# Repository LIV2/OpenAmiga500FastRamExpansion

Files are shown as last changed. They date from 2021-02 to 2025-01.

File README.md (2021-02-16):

# OpenAmiga500FastRamExpansion
OpenAmiga500FastRamExpansion is an Open Hardware 4/8 MB Fast RAM Expansion for the Commodore Amiga 500 Computer.

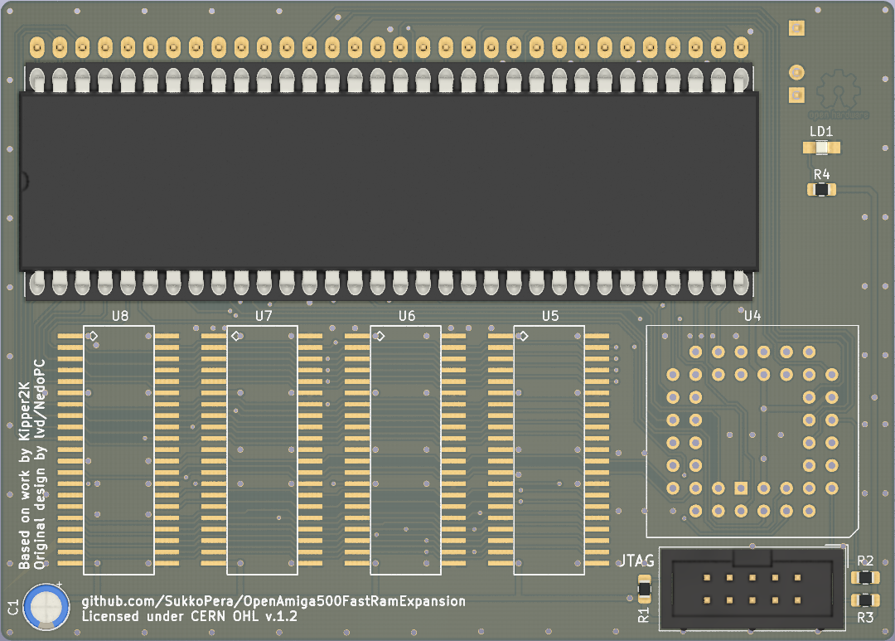
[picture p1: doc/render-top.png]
Board


### Summary
Most low-end Amiga models only came with *Chip RAM*. "Big Box" models allowed for a different type of memory to be installed, known as *Fast RAM*, where *fast* means that it's dedicated to the main processor, so that it doesn't have to compete with the other chips in order to gain access to it (as is the case with Chip RAM). While both Chip and Fast RAM are limited in size, you can have at least a few MB of the latter on all Amigas (usually up to 8), while the former can never exceed 2 MB.

OpenAmiga500FastRamExpansion will allow you to add up to 4 or 8 MB of Fast RAM to your Amiga 500. This way you will be able to run more applications at once and more quickly. If you combine it with [a chip RAM expansion](http://eab.abime.net/showthread.php?t=85395), you will also be able to run almost all games supported by WHDLoad, pushing your Amiga to its limits. 

OpenAmiga500FastRamExpansion is basically a clone of [a RAM expansion produced by Kipper2K a few years ago](http://eab.abime.net/showthread.php?t=64218), based on [an earlier design by lvd/NedoPC](http://lvd.nedopc.com/Projects/a600_8mb/index.html). He has since stopped producing and selling these cards and I thought it was a pity that he didn't open his designs and actually took all of them down, as this card is quite cheap to build and really useful. So I set about recreating it from scratch.

### Features
- Plug & play Autoconfig friendly - This board can work with other autoconfig devices without needing any extra wires.
- Auto-sizing - When placed at the end of the Autoconfig chain (using the CFGIN jumper) the board will auto-size to fit within the 8MB Autoconfig space even if another device is already using some of the space.
- Force 4MB mode - Closing the 4MB jumper will set the maximum size of this expansion to 4MB.
- Compatible with A500/1000/2000/CDTV

### Memory Compatibility
The required RAM Type is 16 Mbit (1M×16) DRAM in the SOJ-42 package with up to 70-80 ns access time. It is 5v-only DRAM (not SD(!)RAM) often found in old 72-pin SIMMs, EDO chips might work or not. All chips having *8160* in their part number should be OK.

|Model |Maker |Tested |Working |Data Sheet |Notes |
|---|---|:---:|:---:|:---:|---|
|AS4C1M116E5 |Alliance |No  | | | |
|GM71C18160 |Hynix/LGS |Yes|Yes|PDF |Tested by lvd in his original project |
|HY5118164B |Hynix |No  | | | |
|KM416C1200AJ |SEC |Yes|Yes| |Reported working by Ronald Baer |
|KM416C1204AJ/BJ|SEC |Yes|Yes|PDF (http://pdf.datasheetcatalog.com/datasheet_pdf/samsung-electronic/KM416C1004BJ-45_to_KM416V1204BT-L7.pdf) |Reported working by screwbreaker |
|MSM5118160 |OKI |Yes|Yes|PDF |Tested by lvd in his original project |
|TMS41860DZ |Texas Instruments|Yes|Yes| |Reported working by Ronald Baer |
|TMS41869DZ |Texas Instruments|No  | | | |
|4218160 |NEC |Yes|Yes| |Reported working by Ronald Baer |
|4218165 |NEC |Yes|Yes|PDF (https://www.datasheetarchive.com/pdf/download.php?id=5f10686e336fc0bb44481c8b0f0340b8d05d8a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) |Tested by SukkoPera |

RAM chips can either be soldered directly to the board or installed in sockets. While soldering the chips might not be trivial for the unexperienced, sockets for the SOJ-42 package are hard to find and not really easier to solder either, so the choice is up to you.

### Bill of materials
|Component|Location|QTY|Link|Remarks|
|---|---|---|---|---|
|DRAM|U5-8|4|-|eBay/Aliexpress etc.|
|Machined pin headers|J1|2|-|2x 32-pin machined pin headers|
|Machined pin sockets|U1|2|-|2x 32-pin machined pin sockets|
|ATF1504AS-10JU44|U4|1|[Mouser](https://www.mouser.com/ProductDetail/556-AF1504AS10JU44)||
|74AHCT157|U2,U3,U9|3|[Mouser](https://www.mouser.com/ProductDetail/595-SN74AHCT157DR)||
|74ALS257|U10|1|[Mouser](https://www.mouser.com/ProductDetail/595-SN74ALS257AD)|Timing critical - do not substitute!|
|74AHCT00|U11|1|[Mouser](https://www.mouser.com/ProductDetail/595-SN74AHCT00DRE4)|Timing critical - do not substitute!|
|100nF Ceramic Capacitor - 0805|C2-22|21|[Mouser](https://www.mouser.com/ProductDetail/581-08055C104K)||
|10uF Electrolytic Capacitor - 0805|C1|1|[Mouser](https://www.mouser.com/ProductDetail/80-ESK106M016AC3AA)||
|4.7K Resistor - 0805|R5-8|4|[Mouser](https://www.mouser.com/ProductDetail/754-RR1220P-472D)||
|10K Resistor - 0805|R1-3|3|[Mouser](https://www.mouser.com/ProductDetail/754-RR1220P-103D)||

### Assembly and Installation
Normally it is not necessary to mount all the decoupling capacitors. I usually skip C4, C5, C9, C12, C15 and C18. Maybe C1 can be left out as well if you have a good power supply, your choice. R4 must be chosen according to the particular led you will be using for LD1. Actually you are free to skip LD1 and R4 altogether, if you hate power LEDs.

After everything has been soldered, you will need to program the CPLD. Whenever you do so, **make sure to carefully remove the board from your Amiga, or you might risk damaging it**. You can find the firmware [here](https://github.com/SukkoPera/OpenAmiga500FastRamExpansion/tree/master/firmware), along with instructions on how to flash it. You can provide power through the pads of C1 if you need to do so.

For a 4MB only board solder solder U7 and U8 only and close the 4MB jumper.

When assembly is complete, open your A500 and remove the top shield. Carefully remove the CPU (largest chip at bottom left of the board), using a chip extractor or a small flat screwdriver, taking care not to break/bend any pins. Plug it on the board, matching the orientation, and plug the whole board in the CPU socket.

Before reassembling your case, I recommend to run [SysTest/Amiga Test Kit](https://github.com/keirf/Amiga-Stuff). Use the Memory option (<kbd>F1</kbd>), it must show 4/8 MB of Fast RAM. Then start the Memory Test (<kbd>F1</kbd> again) and let it run for 50-100 rounds: if it doesn't find any errors, you are probably good to go. If you get any errors, check your solder joints, starting from actual the RAM chips, as the SOJ package is not very hand-soldering-friendly.

### Configuration
OpenAmiga500FastRamExpansion can be forced into 4MB mode by closing the 4MB jumper 

By default the board will be the first autoconfig device configured but this can be changed by connecting this boards CFGIN pin to the CFGOUT pin of another autoconfig board, or to one of the cfgin/out connections of U606 in an Amiga 2000. 

If your system includes other Fast RAM devices or RTG graphics you may need to connect CFGIN to the end of your autoconfig chain (A2000 U606 pin 8) or close the 4MB jumper. 

### Troubleshooting
- Yellow screen: Due to an Kickstart bug you may see a yellow screen if there is more than 8MB of autoconfig devices in your system. Connect the CFGIN pin so this board is at the end of the chain or close the 4MB jumper.
- Red screen showing "Status: Defective": This means the board was detected but the RAM test failed. Check the soldering of the RAM chips
### License
The OpenAmiga500FastRamExpansion documentation, including the design itself, is copyright &copy; SukkoPera 2019. 

OpenAmiga500FastRamExpansion is Open Hardware licensed under the [CERN OHL v. 1.2](http://ohwr.org/cernohl).

You may redistribute and modify this documentation under the terms of the CERN OHL v.1.2. This documentation is distributed *as is* and WITHOUT ANY EXPRESS OR IMPLIED WARRANTIES whatsoever with respect to its functionality, operability or use, including, without limitation, any implied warranties OF MERCHANTABILITY, SATISFACTORY QUALITY, FITNESS FOR A PARTICULAR PURPOSE or infringement. We expressly disclaim any liability whatsoever for any direct, indirect, consequential, incidental or special damages, including, without limitation, lost revenues, lost profits, losses resulting from business interruption or loss of data, regardless of the form of action or legal theory under which the liability may be asserted, even if advised of the possibility or likelihood of such damages.

A copy of the full license is included in file [LICENSE.pdf](LICENSE.pdf), please refer to it for applicable conditions. In order to properly deal with its terms, please see file [LICENSE_HOWTO.pdf](LICENSE_HOWTO.pdf).

The contact points for information about manufactured Products (see section 4.2) are listed in file [PRODUCT.md](PRODUCT.md).

Any modifications made by Licensees (see section 3.4.b) shall be recorded in file [CHANGES.md](CHANGES.md).

The Documentation Location of the original project is https://github.com/SukkoPera/OpenAmiga500FastRamExpansion/.

### Support the Project
Since the project is open you are free to get the PCBs made by your preferred manufacturer, however in case you want to support the development, you can order them from PCBWay through this link:

PCB from PCBWay (https://www.pcbway.com/project/shareproject/OpenAmiga500FastRamExpansion_V1.html)

You get my gratitude and cheap, professionally-made and good quality PCBs, I get some credit that will help with this and [other projects](https://www.pcbway.com/project/member/shareproject/?bmbid=41100). You won't even have to worry about the various PCB options, it's all pre-configured for you!

Also, if you still have to register to that site, [you can use this link](https://www.pcbway.com/setinvite.aspx?inviteid=41100) to get some bonus initial credit (and yield me some more).

Again, if you want to use another manufacturer, feel free to, don't feel obligated :). But then you can buy me a coffee if you want:

<a href='https://ko-fi.com/L3L0U18L' target='_blank'>Buy Me a Coffee at ko-fi.com</a>

### Get Help
If you need help or have questions, you can join [the official Telegram group](https://t.me/joinchat/HUHdWBC9J9JnYIrvTYfZmg).

### Thanks
- lvd for the initial design and the support he gave me during development
- Kipper2K for making his boards
- majinga for helping with the testing

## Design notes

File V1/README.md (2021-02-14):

# OpenAmiga500FastRamExpansion
OpenAmiga500FastRamExpansion is an Open Hardware 4/8 MB Fast RAM Expansion for the Commodore Amiga 500 Computer.

Board

### Summary
Most low-end Amiga models only came with *Chip RAM*. "Big Box" models allowed for a different type of memory to be installed, known as *Fast RAM*, where *fast* means that it's dedicated to the main processor, so that it doesn't have to compete with the other chips in order to gain access to it (as is the case with Chip RAM). While both Chip and Fast RAM are limited in size, you can have at least a few MB of the latter on all Amigas (usually up to 8), while the former can never exceed 2 MB.

OpenAmiga500FastRamExpansion will allow you to add 4 or 8 MB of Fast RAM to your Amiga 500. This way you will be able to run more applications at once and more quickly. If you combine it with [a chip RAM expansion](http://eab.abime.net/showthread.php?t=85395), you will also be able to run almost all games supported by WHDLoad, pushing your Amiga to its limits. The Fast RAM will be mapped to `$200000-$9fffff` (`$200000-$5fffff` for the 4 MB version).

OpenAmiga500FastRamExpansion is basically a clone of [a RAM expansion produced by Kipper2K a few years ago](http://eab.abime.net/showthread.php?t=64218), based on [an earlier design by lvd/NedoPC](http://lvd.nedopc.com/Projects/a600_8mb/index.html). He has since stopped producing and selling these cards and I thought it was a pity that he didn't open his designs and actually took all of them down, as this card is quite cheap to build and really useful. So I set about recreating it from scratch.

### Memory Compatibility
The required RAM Type is 16 Mbit (1M×16) DRAM in the SOJ-42 package with up to 70-80 ns access time. It is 5v-only DRAM (not SD(!)RAM) often found in old 72-pin SIMMs, EDO chips might work or not. All chips having *8160* in their part number should be OK.

|Model |Maker |Tested |Working |Data Sheet |Notes |
|---|---|:---:|:---:|:---:|---|
|AS4C1M116E5 |Alliance |No  | | | |
|GM71C18160 |Hynix/LGS |Yes|Yes|PDF |Tested by lvd in his original project |
|HY5118164B |Hynix |No  | | | |
|KM416C1200AJ |SEC |Yes|Yes| |Reported working by Ronald Baer |
|KM416C1204AJ/BJ|SEC |Yes|Yes|PDF (http://pdf.datasheetcatalog.com/datasheet_pdf/samsung-electronic/KM416C1004BJ-45_to_KM416V1204BT-L7.pdf) |Reported working by screwbreaker |
|MSM5118160 |OKI |Yes|Yes|PDF |Tested by lvd in his original project |
|TMS41860DZ |Texas Instruments|Yes|Yes| |Reported working by Ronald Baer |
|TMS41869DZ |Texas Instruments|No  | | | |
|4218160 |NEC |Yes|Yes| |Reported working by Ronald Baer |
|4218165 |NEC |Yes|Yes|PDF (https://www.datasheetarchive.com/pdf/download.php?id=5f10686e336fc0bb44481c8b0f0340b8d05d8a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) |Tested by SukkoPera |

RAM chips can either be soldered directly to the board or installed in sockets. While soldering the chips might not be trivial for the unexperienced, sockets for the SOJ-42 package are hard to find and not really easier to solder either, so the choice is up to you.

### Assembly and Installation
Normally it is not necessary to mount all the decoupling capacitors. I usually skip C4, C5, C9, C12, C15 and C18. Maybe C1 can be left out as well if you have a good power supply, your choice. R4 must be chosen according to the particular led you will be using for LD1. Actually you are free to skip LD1 and R4 altogether, if you hate power LEDs.

After everything has been soldered, you will need to program the CPLD. Whenever you do so, **make sure to carefully remove the board from your Amiga, or you might risk damaging it**. You can find the firmware [here](https://github.com/SukkoPera/OpenAmiga500FastRamExpansion/tree/master/firmware), along with instructions on how to flash it. You can provide power through the pads of C1 if you need to do so.

Make sure to use the correct firmware version, according to how many chips you soldered on the board! For the 4 MB version, solder U7 and U8 only and use the dedicated firmware.

When assembly is complete, open your A500 and remove the top shield. Carefully remove the CPU (largest chip at bottom left of the board), using a chip extractor or a small flat screwdriver, taking care not to break/bend any pins. Plug it on the board, matching the orientation, and plug the whole board in the CPU socket.

Before reassembling your case, I recommend to run [SysTest/Amiga Test Kit](https://github.com/keirf/Amiga-Stuff). Use the Memory option (<kbd>F1</kbd>), it must show 4/8 MB of Fast RAM. Then start the Memory Test (<kbd>F1</kbd> again) and let it run for 50-100 rounds: if it doesn't find any errors, you are probably good to go. If you get any errors, check your solder joints, starting from actual the RAM chips, as the SOJ package is not very hand-soldering-friendly.

### Limitations
OpenAmiga500FastRamExpansion only has a partial implementation of the AutoConfig protocol. This has the following consequences:
- On the A500 it will only work if nothing is connected to the side expansion port (or if whatever is connected does NOT use AutoConfig).
- On the A2000 it will only work if nothing is installed in the first Zorro expansion slot (again: or if whatever you installed there does not use AutoConfig).
- On the CDTV it just won't work (since the DMAC uses AutoConfig and is built-in.)

The only way to get around these limitations is flashing an alternative firmware on the board which does not use AutoConfig, but then you will have to add the RAM manually in Workbench, using the `addmem` utility. More on this soon.

### License
The OpenAmiga500FastRamExpansion documentation, including the design itself, is copyright &copy; SukkoPera 2019.

OpenAmiga500FastRamExpansion is Open Hardware licensed under the [CERN OHL v. 1.2](http://ohwr.org/cernohl).

You may redistribute and modify this documentation under the terms of the CERN OHL v.1.2. This documentation is distributed *as is* and WITHOUT ANY EXPRESS OR IMPLIED WARRANTIES whatsoever with respect to its functionality, operability or use, including, without limitation, any implied warranties OF MERCHANTABILITY, SATISFACTORY QUALITY, FITNESS FOR A PARTICULAR PURPOSE or infringement. We expressly disclaim any liability whatsoever for any direct, indirect, consequential, incidental or special damages, including, without limitation, lost revenues, lost profits, losses resulting from business interruption or loss of data, regardless of the form of action or legal theory under which the liability may be asserted, even if advised of the possibility or likelihood of such damages.

A copy of the full license is included in file [LICENSE.pdf](LICENSE.pdf), please refer to it for applicable conditions. In order to properly deal with its terms, please see file [LICENSE_HOWTO.pdf](LICENSE_HOWTO.pdf).

The contact points for information about manufactured Products (see section 4.2) are listed in file [PRODUCT.md](PRODUCT.md).

Any modifications made by Licensees (see section 3.4.b) shall be recorded in file [CHANGES.md](CHANGES.md).

The Documentation Location of the original project is https://github.com/SukkoPera/OpenAmiga500FastRamExpansion/.

### Support the Project
Since the project is open you are free to get the PCBs made by your preferred manufacturer, however in case you want to support the development, you can order them from PCBWay through this link:

PCB from PCBWay (https://www.pcbway.com/project/shareproject/OpenAmiga500FastRamExpansion_V1.html)

You get my gratitude and cheap, professionally-made and good quality PCBs, I get some credit that will help with this and [other projects](https://www.pcbway.com/project/member/shareproject/?bmbid=41100). You won't even have to worry about the various PCB options, it's all pre-configured for you!

Also, if you still have to register to that site, [you can use this link](https://www.pcbway.com/setinvite.aspx?inviteid=41100) to get some bonus initial credit (and yield me some more).

Again, if you want to use another manufacturer, feel free to, don't feel obligated :). But then you can buy me a coffee if you want:

<a href='https://ko-fi.com/L3L0U18L' target='_blank'>Buy Me a Coffee at ko-fi.com</a>

### Get Help
If you need help or have questions, you can join [the official Telegram group](https://t.me/joinchat/HUHdWBC9J9JnYIrvTYfZmg).

### Thanks
- lvd for the initial design and the support he gave me during development
- Kipper2K for making his boards
- majinga for helping with the testing

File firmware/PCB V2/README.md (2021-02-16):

# Firmware
Before installing the board into your Amiga, you will need to program the CPLD chip.

The firmware is the same as the original project by lvd. It has been copied here for convenience, but it is unmodified.

The firmware was originally developed for Altera `EPM7064SLC44` CPLDs.

Atmel/Microchip makes compatible devices under the `ATF1504` series, so the `ATF1504AS-10JC44` can be used as an alternative, which is easier to find nowadays (-10J*U*44 is fine as well).

## Flashing the firmware

### Altera EPM7064SLC44
You will need to load the `.POF` file in `quartus_pgm` and flash it using one of the cheap USB Blaster programmer clones you can find everywhere.

*NOTE: One user recommends NOT to use the auto-detect button as it will add two ICs to the window. Just select the USB Blaster hardware and load the .POF file (make sure to check only Program/Configure + Verify!). Then hit the Start button to flash.*

### Atmel/Microchip ATF1504AS-10JC44 (Official way)
You can program the .JED file using the [ATDH1150USB](https://www.microchip.com/DevelopmentTools/ProductDetails/ATDH1150USB) programmer.

### Atmel/Microchip ATF1504AS-10JC44 (Cheaper and hackish way)
These days you will only find the ATF1504AS-10JC44 (or -10JU44) on the market, but, if you read the above, you will know that you will need to buy a >50€ programmer to program it, which doesn't sound reasonable, as this will most likely only need to be done once. Besides, all the tools mentioned above are Windows-only so if you are a Linux user like me, you're pretty screwed. Luckily, there is a solution that allows flashing the Atmel chip with the cheap USB Blaster clones. I have developed and tested it under Linux, but it should also work on Windows and OS X.

First of all you need to power the board. JTAG programmers are not supposed to provide power, hence you need to do so separately. The board does not have a dedicated power connector, but you can use the pads of C1 (which I don't recommend installing, unless you have stability issues) or pins 2 (GND) and 4 (VCC) of the IDC connector. The board needs 5V, I usually take those from an Arduino board but feel free to use whatever suits you.

On the software side, you will need [UrJTAG](http://urjtag.sourceforge.net). I have only tested version 2018.09, others might work or not. I am not sure this version is readily available in binary format, so you might have to compile it from sources.

You will also need to get the [BSDL (Boundary Scan Description Language) files for the 1504 CPLDs](http://ww1.microchip.com/downloads/en/DeviceDoc/1504bsdl.zip). Download the zip file, uncompress it anywhere you like and take note of the path, you will need it later.

Finally, you will need the firmware in SVF format, available in this folder.

Now you are ready for the actual flashing, so connect your USB Blaster to the IDC connector on the board and plug it into an USB port on your PC. Then run urjtag as follows:

```
sukko@shockwave firmware $ sudo jtag

UrJTAG 2018.09 #
Copyright (C) 2002, 2003 ETC s.r.o.
Copyright (C) 2007, 2008, 2009 Kolja Waschk and the respective authors

UrJTAG is free software, covered by the GNU General Public License, and you are
welcome to change it and/or distribute copies of it under certain conditions.
There is absolutely no warranty for UrJTAG.

warning: UrJTAG may damage your hardware!
Type "quit" to exit, "help" for help.

jtag> cable UsbBlaster
Connected to libftdi driver.
```

This means that your USB Blaster was detected correctly. Let's load the BSDL files, this is where you will need to use the path you took note of at the beginning:
```
jtag> bsdl path <path>
jtag>
```

Now we can scan the JTAG chain:
```
jtag> detect
IR length: 10
Chain length: 1
Device Id: 00000001010100000010000000111111 (0x0150203F)
  Filename:     bsdl/1504AS_A44.bsd
```

This means that the CPLD was found and it is ready to be programmed. If you get no output at this step, try disconnecting and reconnecting the USB Blaster or power to the board. If the chip gets detected but it is reported as unsupported, check that you downloaded the correct BSDL files. Then start the flashing:
```
jtag> svf OpenAmiga500FastRAMV2.svf progress stop
warning: unimplemented mode 'ABSENT' for TRST
detail: Parsing   3660/3668 ( 99%)detail:
detail: Scanned device output matched expected TDO values.
```

If you get the above output, the flashing was successful and you can start using your board. If instead you get something like:
```
jtag> svf OpenAmiga500FastRAMV2.svf
warning: unimplemented mode 'ABSENT' for TRST
Error svf: mismatch at position 64 for TDO
 in input file between line 2196 col 1 and line 2198 col 32
```

Then there was an error during the flashing, check your wiring, power and try again.

#### USB Blaster Clones
You are recommended to get **a full-size Altera USB Blaster clone**, i.e. one of these:

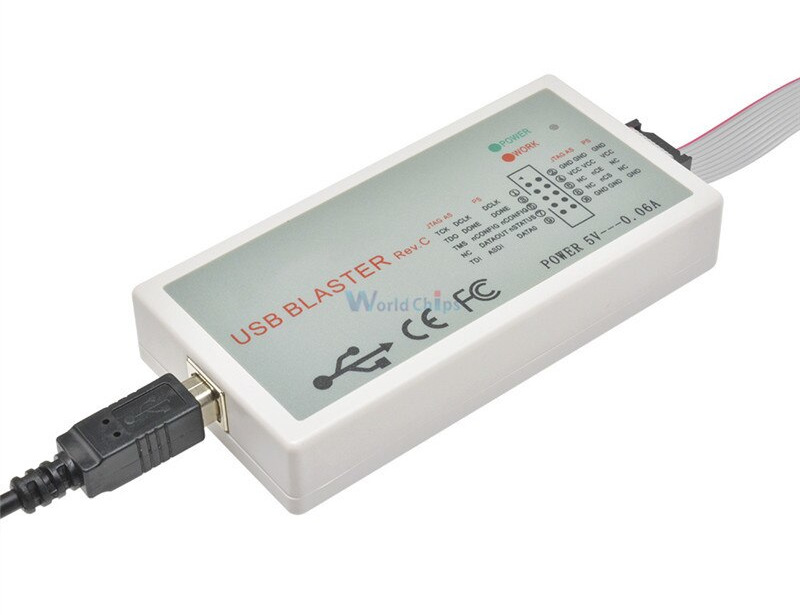
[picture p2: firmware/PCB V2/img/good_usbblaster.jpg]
Full-Size


Note the *Rev.C*: I'm not sure if it is crucial, but the one I have says so and is working very well.

Do **NOT** buy this:

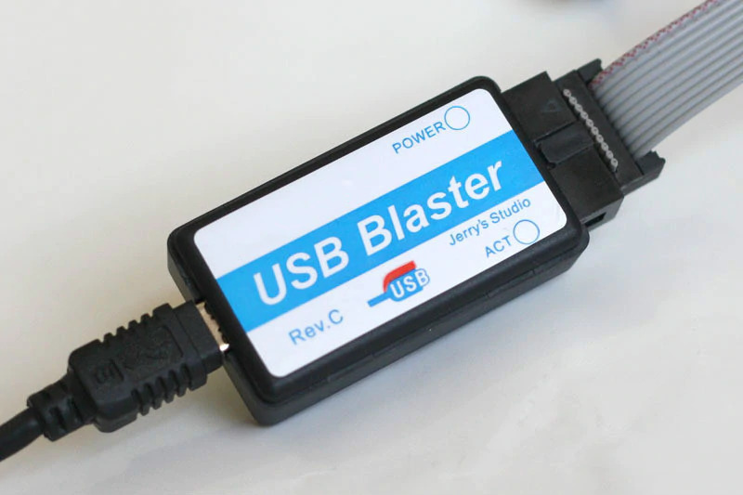
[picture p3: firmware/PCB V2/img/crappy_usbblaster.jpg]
Smaller


It does not work correctly, as it always hangs between 47% and 49% of the flashing process.

## Windows considerations
I have managed to build a Windows binary of UrJTAG with only the minimum options needed to program these CPLDs through a USB Blaster. It was tested by a couple of users and seemed to be working fine. A user even automated the procedure, so now you can just download [the UrJTAG.zip file from the windows folder](windows/UrJTAG.zip), unzip it and double click on the `runme.bat` script (with the programmer and board already connected to your PC): this should guide you through the whole flashing process.

I hope this works for you, but please note that **it is unsupported**, as I have no computers running Windows.

## Tinkering with the firmware
The firmware was developed with [Quartus 13.0 SP1 web edition](https://fpgasoftware.intel.com/13.0sp1/), you will also need the MAX 7000 device support package listed on that page

### POF => JED
Quartus will produce a .POF file. This can be converted to a .JED file for Atmel devices through [Microchip's POF2JED utility](https://www.microchip.com/design-centers/programmable-logic/spld-cpld/tools/software/pof2jed), which is Windows-only unfortunately.

### JED => SVF
An SVF file can be produced using [Microchip's ATMISP tool](https://www.microchip.com/design-centers/programmable-logic/spld-cpld/tools/software/atmisp), which is also Windows-only.

### Used chips from China
The chips can be pre-used if you bought your ATF1504AS from China. Sometimes JTAG interface is disabled on them, preventing normal JTAG operations.

To enable JTAG, remove U11 and connect +12V power through a 2.2kOhm resistor to pin 44 on the CPLD. Afterwards flash the `atf1504as_erase.svf` file to the CLPD. Then you can refit U11 and follow the normal programming procedures.

## Thanks
- *lvd* for providing most of the above information and helping me come up with the Linux flashing procedure.
- *majinga* and *go0se* for testing and helping improve this procedure.
- EAB forum user *katarakt* for the note on Quartus.
- Szymon Roslowski and Graham P. for testing and improving the Windows package.

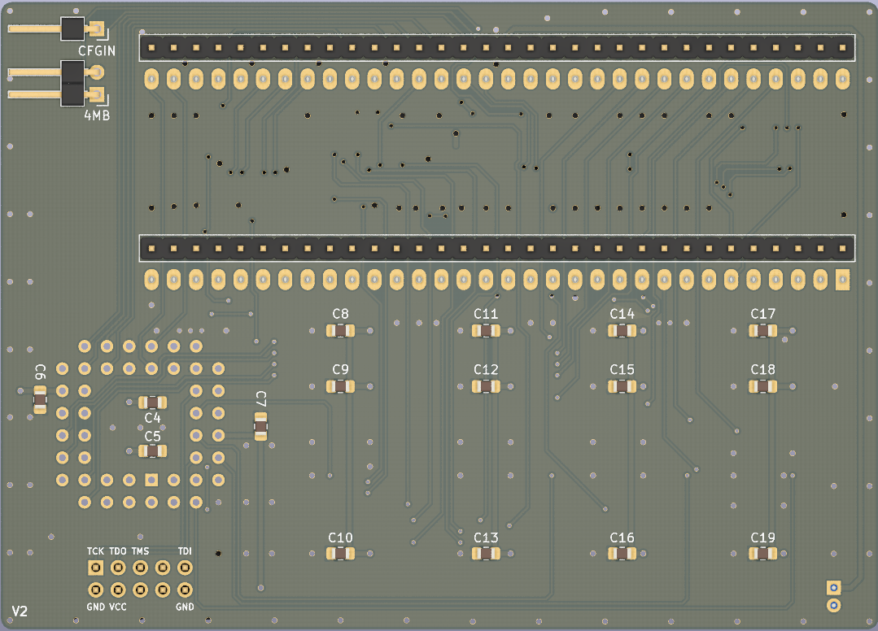
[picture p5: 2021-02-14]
doc/render-bottom.png

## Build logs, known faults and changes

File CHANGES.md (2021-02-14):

## CHANGES

Any modifications to the OpenAmiga500FastRamExpansion design and documentation made by any Licensee MUST be noted in this file, as per *section 3.4.b* of the [license](LICENSE.pdf).

### 04/02/2021 - Matt Harlum (LIV2)
* Moved MA0/1 to another 74157
* Added _cfgin pin
* Added autoconfig hiding circuit

### 13/02/2021 - Matt Harlum (LIV2)
* Added /AS to the autoconfig hiding circuit
* Add 4MB jumper
* Add Firmware source and binaries
* Update documentation for board V2

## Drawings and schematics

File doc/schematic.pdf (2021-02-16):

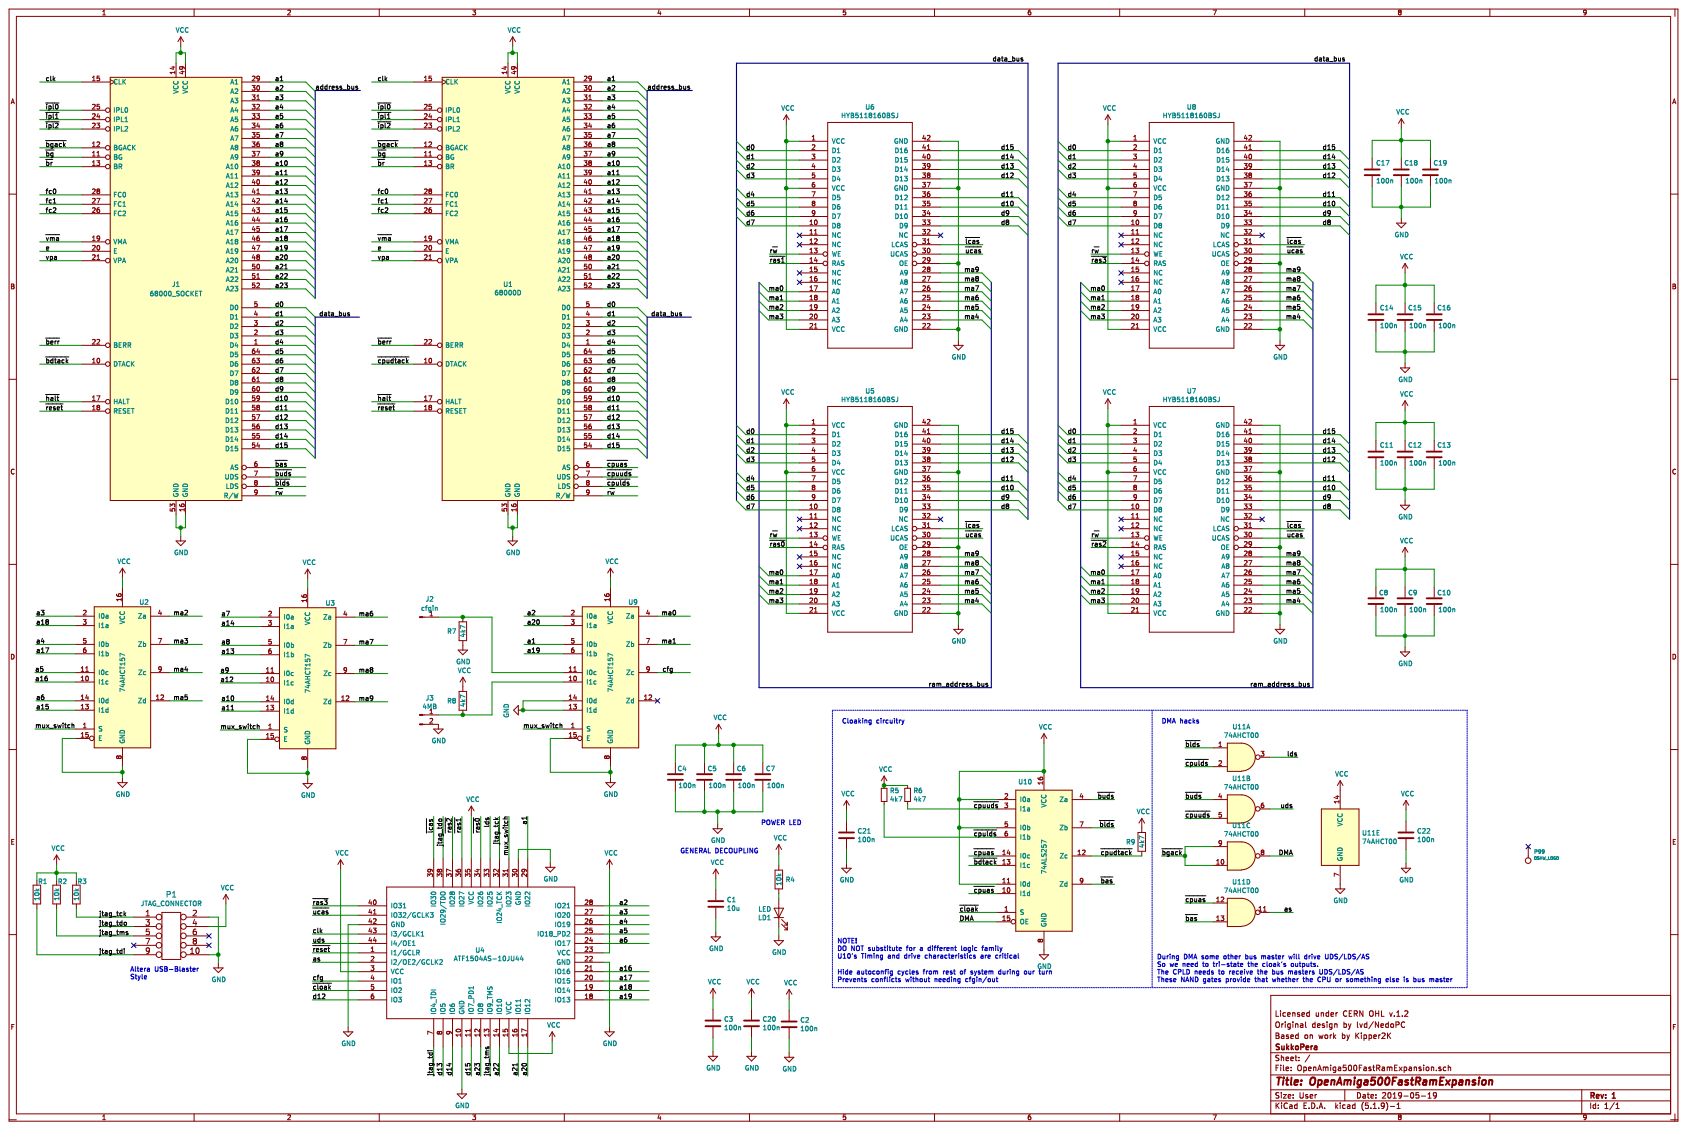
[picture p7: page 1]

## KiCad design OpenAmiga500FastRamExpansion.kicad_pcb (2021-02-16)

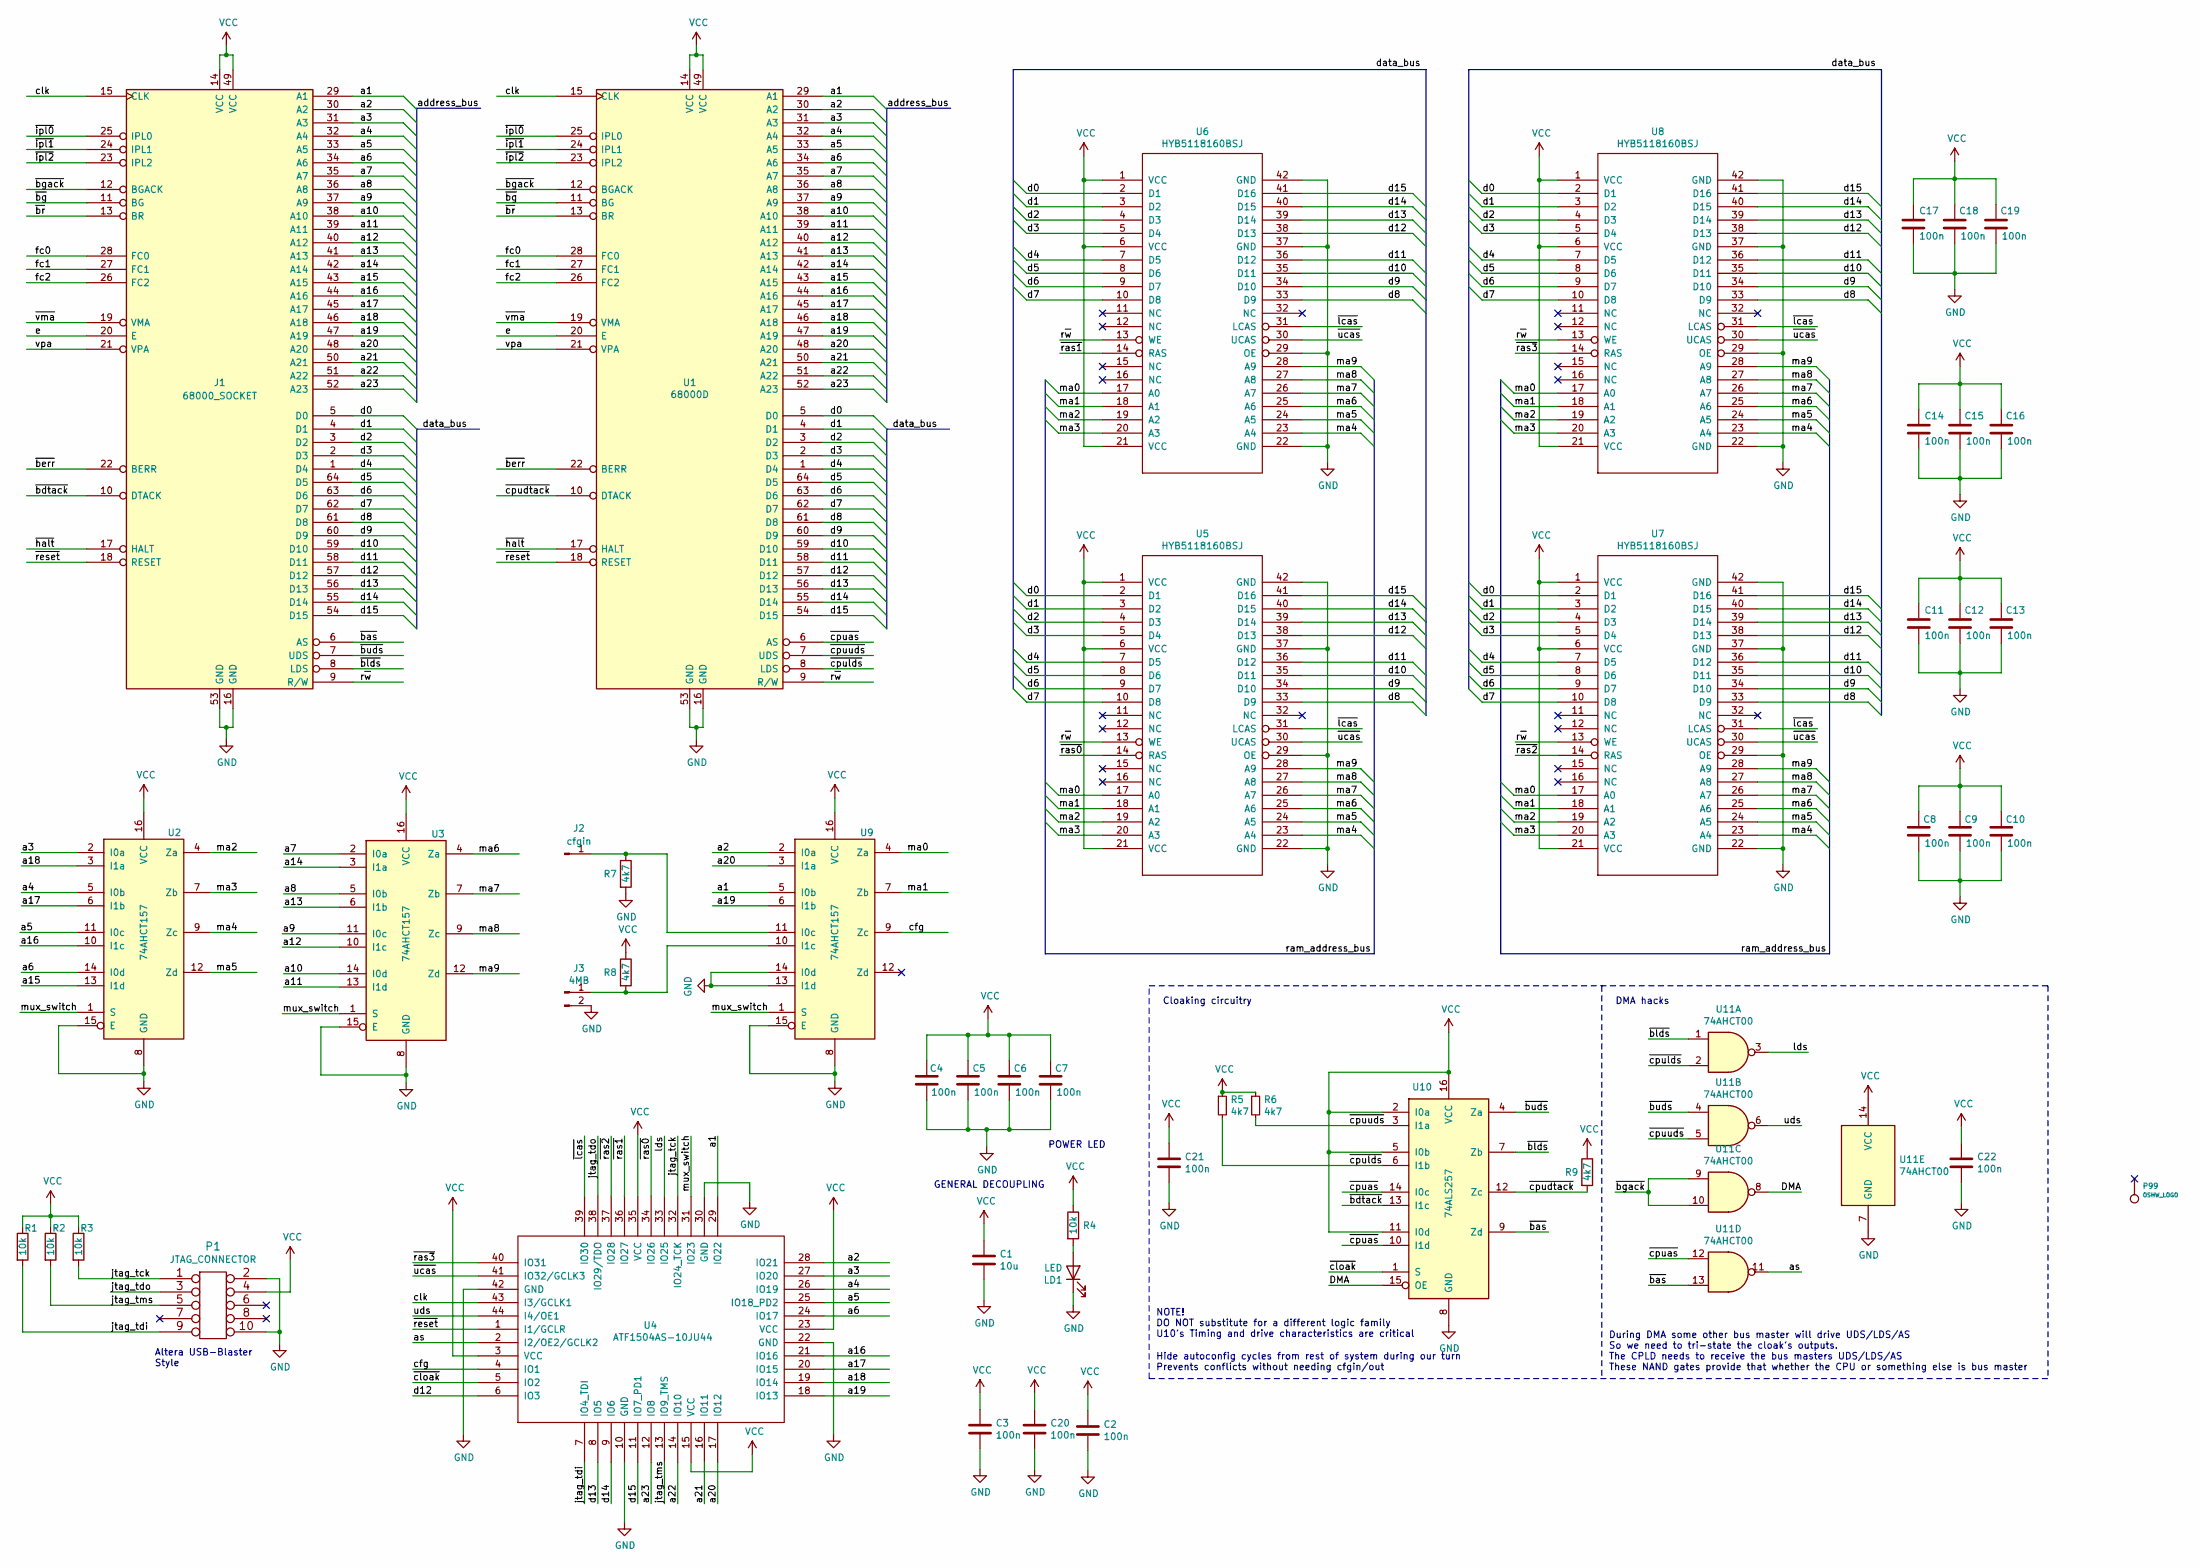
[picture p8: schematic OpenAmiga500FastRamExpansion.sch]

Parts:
C1: 10u; CP_Radial_D5.0mm_P2.00mm
C2, C3, C4, C5, C6, C7, C8, C9, C10, C11, C12, C13, C14, C15, C16, C17, C18, C19: 100n; C_0805_2012Metric_Pad1.15x1.40mm_HandSolder
C20, C21, C22: 100n; C_0805_2012Metric_Pad1.18x1.45mm_HandSolder
J1: 68000_SOCKET; DIP-64_W22.86mm_Socket_LongPads_Socket
J2: cfgin; PinHeader_1x01_P2.54mm_Horizontal
J3: 4MB; PinHeader_1x02_P2.54mm_Horizontal
LD1: LED; LED_0805_HandSoldering_ModSilkS
P1: JTAG_CONNECTOR; IDC-Header_2x05_P2.54mm_Vertical
P99: OSHW_LOGO; OSHW-Logo2_7.3x6mm_Copper
R1, R2, R3, R4: 10k; R_0805_2012Metric_Pad1.15x1.40mm_HandSolder
R5, R6, R7, R8, R9: 4k7; R_0805_2012Metric_Pad1.20x1.40mm_HandSolder
U1: 68000D; DIP-64_W22.86mm_Socket_LongPads_IC
U2, U3, U9: 74AHCT157; SOIC-16_3.9x9.9mm_P1.27mm
U4: ATF1504AS-10JU44; PLCC-44_THT-Socket
U5, U6, U7, U8: HYB5118160BSJ; SOJ-42-LongPads
U10: 74ALS257; SOIC-16_3.9x9.9mm_P1.27mm
U11: 74AHCT00; SOIC-14_3.9x8.7mm_P1.27mm

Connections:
/DMA: U10.15 (OE), U11.8
/a1: J1.29 (A1), U1.29 (A1), U4.29 (IO22), U9.5 (I0b)
/a2: J1.30 (A2), U1.30 (A2), U4.28 (IO21), U9.2 (I0a)
/a3: J1.31 (A3), U1.31 (A3), U2.2 (I0a), U4.27 (IO20)
/a4: J1.32 (A4), U1.32 (A4), U2.5 (I0b), U4.26 (IO19)
/a5: J1.33 (A5), U1.33 (A5), U2.11 (I0c), U4.25 (IO18_PD2)
/a6: J1.34 (A6), U1.34 (A6), U2.14 (I0d), U4.24 (IO17)
/a7: J1.35 (A7), U1.35 (A7), U3.2 (I0a)
/a8: J1.36 (A8), U1.36 (A8), U3.5 (I0b)
/a9: J1.37 (A9), U1.37 (A9), U3.11 (I0c)
/a10: J1.38 (A10), U1.38 (A10), U3.14 (I0d)
/a11: J1.39 (A11), U1.39 (A11), U3.13 (I1d)
/a12: J1.40 (A12), U1.40 (A12), U3.10 (I1c)
/a13: J1.41 (A13), U1.41 (A13), U3.6 (I1b)
/a14: J1.42 (A14), U1.42 (A14), U3.3 (I1a)
/a15: J1.43 (A15), U1.43 (A15), U2.13 (I1d)
/a16: J1.44 (A16), U1.44 (A16), U2.10 (I1c), U4.21 (IO16)
/a17: J1.45 (A17), U1.45 (A17), U2.6 (I1b), U4.20 (IO15)
/a18: J1.46 (A18), U1.46 (A18), U2.3 (I1a), U4.19 (IO14)
/a19: J1.47 (A19), U1.47 (A19), U4.18 (IO13), U9.6 (I1b)
/a20: J1.48 (A20), U1.48 (A20), U4.17 (IO12), U9.3 (I1a)
/a21: J1.50 (A21), U1.50 (A21), U4.16 (IO11)
/a22: J1.51 (A22), U1.51 (A22), U4.14 (IO10)
/a23: J1.52 (A23), U1.52 (A23), U4.12 (IO8)
/as: U4.2 (I2/OE2/GCLK2), U11.11
/cfg: U4.4 (IO1), U9.9 (Zc)
/clk: J1.15 (CLK), U1.15 (CLK), U4.43 (I3/GCLK1)
/d0: J1.5 (D0), U1.5 (D0), U5.2 (D1), U6.2 (D1), U7.2 (D1), U8.2 (D1)
/d1: J1.4 (D1), U1.4 (D1), U5.3 (D2), U6.3 (D2), U7.3 (D2), U8.3 (D2)
/d2: J1.3 (D2), U1.3 (D2), U5.4 (D3), U6.4 (D3), U7.4 (D3), U8.4 (D3)
/d3: J1.2 (D3), U1.2 (D3), U5.5 (D4), U6.5 (D4), U7.5 (D4), U8.5 (D4)
/d4: J1.1 (D4), U1.1 (D4), U5.7 (D5), U6.7 (D5), U7.7 (D5), U8.7 (D5)
/d5: J1.64 (D5), U1.64 (D5), U5.8 (D6), U6.8 (D6), U7.8 (D6), U8.8 (D6)
/d6: J1.63 (D6), U1.63 (D6), U5.9 (D7), U6.9 (D7), U7.9 (D7), U8.9 (D7)
/d7: J1.62 (D7), U1.62 (D7), U5.10 (D8), U6.10 (D8), U7.10 (D8), U8.10 (D8)
/d8: J1.61 (D8), U1.61 (D8), U5.33 (D9), U6.33 (D9), U7.33 (D9), U8.33 (D9)
/d9: J1.60 (D9), U1.60 (D9), U5.34 (D10), U6.34 (D10), U7.34 (D10), U8.34 (D10)
/d10: J1.59 (D10), U1.59 (D10), U5.35 (D11), U6.35 (D11), U7.35 (D11), U8.35 (D11)
/d11: J1.58 (D11), U1.58 (D11), U5.36 (D12), U6.36 (D12), U7.36 (D12), U8.36 (D12)
/d12: J1.57 (D12), U1.57 (D12), U4.6 (IO3), U5.38 (D13), U6.38 (D13), U7.38 (D13), U8.38 (D13)
/d13: J1.56 (D13), U1.56 (D13), U4.8 (IO5), U5.39 (D14), U6.39 (D14), U7.39 (D14), U8.39 (D14)
/d14: J1.55 (D14), U1.55 (D14), U4.9 (IO6), U5.40 (D15), U6.40 (D15), U7.40 (D15), U8.40 (D15)
/d15: J1.54 (D15), U1.54 (D15), U4.11 (IO7_PD1), U5.41 (D16), U6.41 (D16), U7.41 (D16), U8.41 (D16)
/e: J1.20 (E), U1.20 (E)
/fc0: J1.28 (FC0), U1.28 (FC0)
/fc1: J1.27 (FC1), U1.27 (FC1)
/fc2: J1.26 (FC2), U1.26 (FC2)
/jtag_tck: P1.1, R3.2, U4.32 (IO24_TCK)
/jtag_tdi: P1.9, R1.2, U4.7 (IO4_TDI)
/jtag_tdo: P1.3, U4.38 (IO29/TDO)
/jtag_tms: P1.5, R2.2, U4.13 (IO9_TMS)
/lds: U4.33 (IO25), U11.3
/ma0: U5.17 (A0), U6.17 (A0), U7.17 (A0), U8.17 (A0), U9.4 (Za)
/ma1: U5.18 (A1), U6.18 (A1), U7.18 (A1), U8.18 (A1), U9.7 (Zb)
/ma2: U2.4 (Za), U5.19 (A2), U6.19 (A2), U7.19 (A2), U8.19 (A2)
/ma3: U2.7 (Zb), U5.20 (A3), U6.20 (A3), U7.20 (A3), U8.20 (A3)
/ma4: U2.9 (Zc), U5.23 (A4), U6.23 (A4), U7.23 (A4), U8.23 (A4)
/ma5: U2.12 (Zd), U5.24 (A5), U6.24 (A5), U7.24 (A5), U8.24 (A5)
/ma6: U3.4 (Za), U5.25 (A6), U6.25 (A6), U7.25 (A6), U8.25 (A6)
/ma7: U3.7 (Zb), U5.26 (A7), U6.26 (A7), U7.26 (A7), U8.26 (A7)
/ma8: U3.9 (Zc), U5.27 (A8), U6.27 (A8), U7.27 (A8), U8.27 (A8)
/ma9: U3.12 (Zd), U5.28 (A9), U6.28 (A9), U7.28 (A9), U8.28 (A9)
/mux_switch: U2.1 (S), U3.1 (S), U4.31 (IO23), U9.1 (S)
/r~w: J1.9 (R/W), U1.9 (R/W), U5.13 (WE), U6.13 (WE), U7.13 (WE), U8.13 (WE)
/uds: U4.44 (I4/OE1), U11.6
/vpa: J1.21 (VPA), U1.21 (VPA)
/~bas: J1.6 (AS), U10.9 (Zd), U11.13
/~bdtack: J1.10 (DTACK), U10.13 (I1c)
/~berr: J1.22 (BERR), U1.22 (BERR)
/~bg: J1.11 (BG), U1.11 (BG)
/~bgack: J1.12 (BGACK), U1.12 (BGACK), U11.9, U11.10
/~blds: J1.8 (LDS), U10.7 (Zb), U11.1
/~br: J1.13 (BR), U1.13 (BR)
/~buds: J1.7 (UDS), U10.4 (Za), U11.4
/~cloak: U4.5 (IO2), U10.1 (S)
/~cpuas: U1.6 (AS), U10.10 (I1d), U10.14 (I0c), U11.12
/~cpudtack: R9.2, U1.10 (DTACK), U10.12 (Zc)
/~cpulds: R5.2, U1.8 (LDS), U10.6 (I1b), U11.2
/~cpuuds: R6.2, U1.7 (UDS), U10.3 (I1a), U11.5
/~halt: J1.17 (HALT), U1.17 (HALT)
/~ipl0: J1.25 (IPL0), U1.25 (IPL0)
/~ipl1: J1.24 (IPL1), U1.24 (IPL1)
/~ipl2: J1.23 (IPL2), U1.23 (IPL2)
/~lcas: U4.39 (IO30), U5.31 (LCAS), U6.31 (LCAS), U7.31 (LCAS), U8.31 (LCAS)
/~ras0: U4.34 (IO26), U5.14 (RAS)
/~ras1: U4.36 (IO27), U6.14 (RAS)
/~ras2: U4.37 (IO28), U7.14 (RAS)
/~ras3: U4.40 (IO31), U8.14 (RAS)
/~reset: J1.18 (RESET), U1.18 (RESET), U4.1 (I1/GCLR)
/~ucas: U4.41 (IO32/GCLK3), U5.30 (UCAS), U6.30 (UCAS), U7.30 (UCAS), U8.30 (UCAS)
/~vma: J1.19 (VMA), U1.19 (VMA)
GND: C1.2, C2.2, C3.2, C4.2, C5.2, C6.2, C7.2, C8.2, C9.2, C10.2, C11.2, C12.2, C13.2, C14.2, C15.2, C16.2, C17.2, C18.2, C19.2, C20.2, C21.2, C22.2, J1.16 (GND), J1.53 (GND), J3.2, LD1.1 (K), P1.2, P1.10, R7.2, U1.16 (GND), U1.53 (GND), U2.8 (GND), U2.15 (E), U3.8 (GND), U3.15 (E), U4.10 (GND), U4.22 (GND), U4.30 (GND), U4.42 (GND), U5.22 (GND), U5.29 (OE), U5.37 (GND), U5.42 (GND), U6.22 (GND), U6.29 (OE), U6.37 (GND), U6.42 (GND), U7.22 (GND), U7.29 (OE), U7.37 (GND), U7.42 (GND), U8.22 (GND), U8.29 (OE), U8.37 (GND), U8.42 (GND), U9.8 (GND), U9.13 (I1d), U9.14 (I0d), U9.15 (E), U10.8 (GND), U11.7 (GND)
unnamed: J2.1, R7.1, U9.11 (I0c)
unnamed: J3.1, R8.2, U9.10 (I1c)
unnamed: LD1.2 (A), R4.2
VCC: C1.1, C2.1, C3.1, C4.1, C5.1, C6.1, C7.1, C8.1, C9.1, C10.1, C11.1, C12.1, C13.1, C14.1, C15.1, C16.1, C17.1, C18.1, C19.1, C20.1, C21.1, C22.1, J1.14 (VCC), J1.49 (VCC), P1.4, R1.1, R2.1, R3.1, R4.1, R5.1, R6.1, R8.1, R9.1, U1.14 (VCC), U1.49 (VCC), U2.16 (VCC), U3.16 (VCC), U4.3 (VCC), U4.15 (VCC), U4.23 (VCC), U4.35 (VCC), U5.1 (VCC), U5.6 (VCC), U5.21 (VCC), U6.1 (VCC), U6.6 (VCC), U6.21 (VCC), U7.1 (VCC), U7.6 (VCC), U7.21 (VCC), U8.1 (VCC), U8.6 (VCC), U8.21 (VCC), U9.16 (VCC), U10.2 (I0a), U10.5 (I0b), U10.11 (I0d), U10.16 (VCC), U11.14 (VCC)

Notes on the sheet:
Altera USB-Blaster Style
Cloaking circuitry
DMA hacks
Hide autoconfig cycles from rest of system during our turn Prevents conflicts without needing cfgin/out
During DMA some other bus master will drive UDS/LDS/AS So we need to tri-state the cloak's outputs. The CPLD needs to receive the bus masters UDS/LDS/AS These NAND gates provide that whether the CPU or something else is bus master
GENERAL DECOUPLING
POWER LED
NOTE! DO NOT substitute for a different logic family U10's Timing and drive characteristics are critical

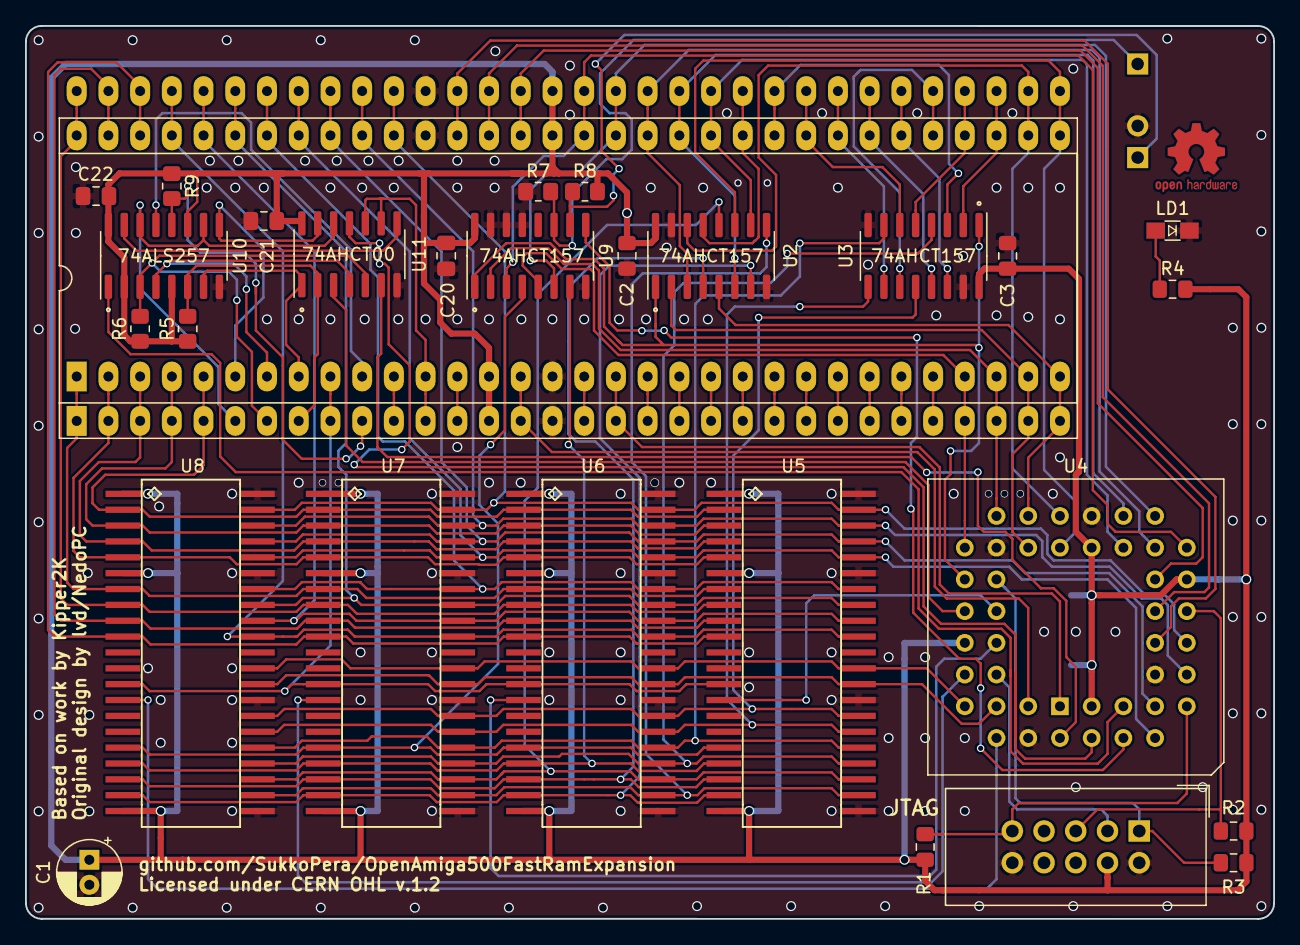
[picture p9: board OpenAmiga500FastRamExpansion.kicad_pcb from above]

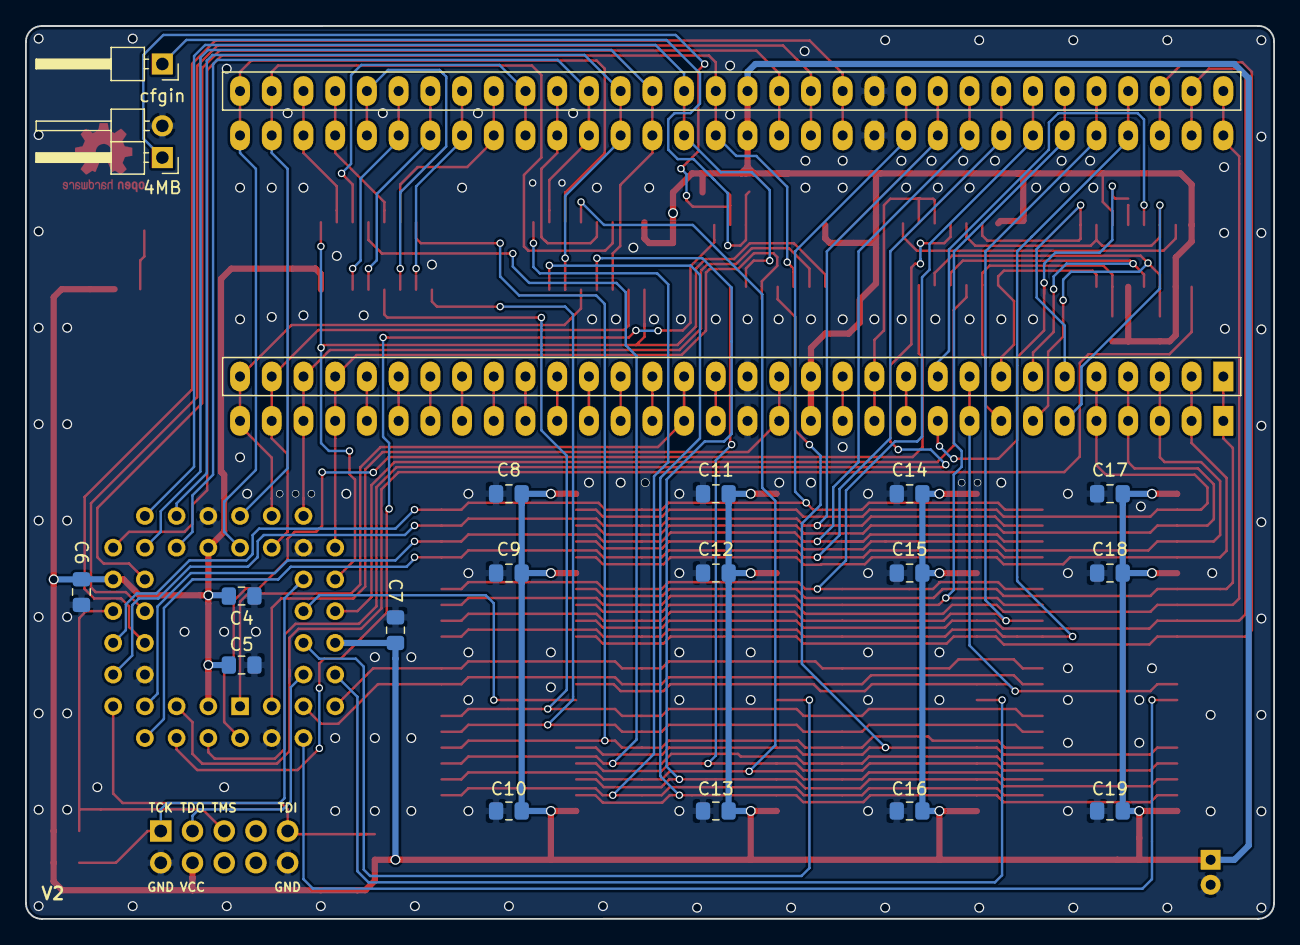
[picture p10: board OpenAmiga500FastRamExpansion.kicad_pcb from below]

Board: 2 copper layers, 100.0 x 71.5 mm, 48 parts (18 on the bottom side), 96 nets.

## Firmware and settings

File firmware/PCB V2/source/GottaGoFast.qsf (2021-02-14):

# -------------------------------------------------------------------------- #
#
# Copyright (C) 1991-2013 Altera Corporation
# Your use of Altera Corporation's design tools, logic functions 
# and other software and tools, and its AMPP partner logic 
# functions, and any output files from any of the foregoing 
# (including device programming or simulation files), and any 
# associated documentation or information are expressly subject 
# to the terms and conditions of the Altera Program License 
# Subscription Agreement, Altera MegaCore Function License 
# Agreement, or other applicable license agreement, including, 
# without limitation, that your use is for the sole purpose of 
# programming logic devices manufactured by Altera and sold by 
# Altera or its authorized distributors.  Please refer to the 
# applicable agreement for further details.
#
# -------------------------------------------------------------------------- #
#
# Quartus II 64-Bit
# Version 13.0.1 Build 232 06/12/2013 Service Pack 1 SJ Web Edition
# Date created = 09:31:48  January 28, 2021
#
# -------------------------------------------------------------------------- #
#
# Notes:
#
# 1) The default values for assignments are stored in the file:
#		GottaGoFast_assignment_defaults.qdf
#    If this file doesn't exist, see file:
#		assignment_defaults.qdf
#
# 2) Altera recommends that you do not modify this file. This
#    file is updated automatically by the Quartus II software
#    and any changes you make may be lost or overwritten.
#
# -------------------------------------------------------------------------- #


set_global_assignment -name FAMILY MAX7000S
set_global_assignment -name DEVICE "EPM7064SLC44-10"
set_global_assignment -name TOP_LEVEL_ENTITY GottaGoFast
set_global_assignment -name ORIGINAL_QUARTUS_VERSION "13.0 SP1"
set_global_assignment -name PROJECT_CREATION_TIME_DATE "09:31:48  JANUARY 28, 2021"
set_global_assignment -name LAST_QUARTUS_VERSION "13.0 SP1"
set_global_assignment -name PROJECT_OUTPUT_DIRECTORY output_files
set_global_assignment -name DEVICE_FILTER_PACKAGE PLCC
set_global_assignment -name DEVICE_FILTER_PIN_COUNT 44
set_global_assignment -name DEVICE_FILTER_SPEED_GRADE 10
set_global_assignment -name ERROR_CHECK_FREQUENCY_DIVISOR "-1"
set_global_assignment -name EDA_SIMULATION_TOOL "ModelSim-Altera (Verilog)"
set_global_assignment -name EDA_OUTPUT_DATA_FORMAT "VERILOG HDL" -section_id eda_simulation
set_global_assignment -name MAX7000_DEVICE_IO_STANDARD TTL
set_location_assignment PIN_1 -to RESETn
set_location_assignment PIN_4 -to CFGINn
set_location_assignment PIN_5 -to CLOAKn
set_location_assignment PIN_6 -to DBUS[12]
set_location_assignment PIN_8 -to DBUS[13]
set_location_assignment PIN_9 -to DBUS[14]
set_location_assignment PIN_11 -to DBUS[15]
set_location_assignment PIN_12 -to ADDR_HI[23]
set_location_assignment PIN_14 -to ADDR_HI[22]
set_location_assignment PIN_16 -to ADDR_HI[21]
set_location_assignment PIN_17 -to ADDR_HI[20]
set_location_assignment PIN_18 -to ADDR_HI[19]
set_location_assignment PIN_19 -to ADDR_HI[18]
set_location_assignment PIN_20 -to ADDR_HI[17]
set_location_assignment PIN_21 -to ADDR_HI[16]
set_location_assignment PIN_24 -to ADDR_LO[6]
set_location_assignment PIN_25 -to ADDR_LO[5]
set_location_assignment PIN_26 -to ADDR_LO[4]
set_location_assignment PIN_27 -to ADDR_LO[3]
set_location_assignment PIN_28 -to ADDR_LO[2]
set_location_assignment PIN_29 -to ADDR_LO[1]
set_location_assignment PIN_43 -to CLK
set_location_assignment PIN_39 -to LCASn
set_location_assignment PIN_33 -to LDS
set_location_assignment PIN_34 -to RAS0n
set_location_assignment PIN_36 -to RAS1n
set_location_assignment PIN_37 -to RAS2n
set_location_assignment PIN_40 -to RAS3n
set_location_assignment PIN_31 -to mux_switch
set_location_assignment PIN_41 -to UCASn
set_location_assignment PIN_44 -to UDS
set_global_assignment -name VERILOG_TEST_BENCH_FILE simulation/modelsim/GottaGoFast.vt
set_global_assignment -name VERILOG_FILE GottaGoFast.v
set_global_assignment -name EDA_TIME_SCALE "1 ps" -section_id eda_simulation
set_global_assignment -name EDA_TEST_BENCH_ENABLE_STATUS TEST_BENCH_MODE -section_id eda_simulation
set_global_assignment -name EDA_NATIVELINK_SIMULATION_TEST_BENCH GottaGoFast_vlg_tst -section_id eda_simulation
set_global_assignment -name EDA_TEST_BENCH_NAME GottaGoFast_vlg_tst -section_id eda_simulation
set_global_assignment -name EDA_DESIGN_INSTANCE_NAME NA -section_id GottaGoFast_vlg_tst
set_global_assignment -name EDA_TEST_BENCH_MODULE_NAME GottaGoFast_vlg_tst -section_id GottaGoFast_vlg_tst
set_global_assignment -name OPTIMIZE_HOLD_TIMING OFF
set_global_assignment -name OPTIMIZE_MULTI_CORNER_TIMING OFF
set_global_assignment -name FITTER_EFFORT "STANDARD FIT"
set_global_assignment -name EDA_TEST_BENCH_FILE simulation/modelsim/GottaGoFast.vt -section_id GottaGoFast_vlg_tst
set_location_assignment PIN_32 -to TCK
set_location_assignment PIN_7 -to TDI
set_location_assignment PIN_38 -to TDO
set_location_assignment PIN_13 -to TMS
set_location_assignment PIN_2 -to AS

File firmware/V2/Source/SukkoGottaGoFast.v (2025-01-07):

/*
GottaGoFast FW for SukkoPera's OpenAmiga500FastRamExpansion
Copyright 2021 Matthew Harlum

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
*/

// Config defines
`define autoconfig     // If disabled RAM is always mapped to $200000-9FFFFF
//`define cdtv         // Uncomment to build CDTV compatible version
//`define Size_4MB     // 4MB Maximum, Only uses memory chips U7 & U8

module SukkoGottaGoFast(
    input CLK,
    input RESETn,
    input UDSn,
    input LDSn,
    input ASn,
    inout [15:12] DBUS,
    input [23:16] ADDR_HI,
    input [6:1]   ADDR_LO,
    output reg mux_switch,
    output RAS0n,
    output RAS1n,
    output RAS2n,
    output RAS3n,
    output UCASn,
    output LCASn,
    output reg MA0,
    output reg MA1
    );

// Memory controller

reg ram_cycle;
reg access_ras;
reg access_ucas;
reg access_lcas;
reg refresh_ras;
reg refresh_cas;
reg [7:0] addr_match;
reg AS_last;
reg RWn;

`ifdef autoconfig
// Autoconfig
localparam [15:0] mfg_id  = 16'h07DB;
localparam [7:0]  prod_id = 8'd03;
localparam [15:0] serial  = 16'd420;

localparam Offer_Block1 = 3'b000,
           Offer_Block2 = 3'b001,
           Offer_Block3 = 3'b010,
           Offer_Block4 = 3'b011,
           SHUTUP       = 3'b100;

wire autoconfig_cycle;
reg shutup = 0;
reg configured;
reg [3:0] data_out;
reg CFGOUTn;

`ifndef cdtv
// Autoconfig bus snooping
//
// For some reason Kickstart 2 and up scan the chain multiple times
// Thanks to this we can snoop on autoconfig cycles and then speak up once
// every other board is done being configured.
// No CFGIN connection needed!
reg [3:0] mfg_bad;
reg snoop_cfg;
reg snoop_cfg_next;
reg [3:0] board_reg00;
reg [3:0] board_reg01;
reg [3:0] snooped_autoconfig_state;
reg autoconfig_setup;
reg [3:0] dbus_latched;

always @(posedge CLK)
begin
  dbus_latched <= DBUS[15:12];
end

always @(posedge UDSn or negedge RESETn)
begin
  if (!RESETn) begin
    snoop_cfg_next <= 1'b0;
    snoop_cfg <= 1'b0;
    mfg_bad <= 'b0;
    snooped_autoconfig_state <= Offer_Block1;
  end else if (ADDR_HI[23:16] == 8'hE8 & RWn) begin
    case (ADDR_LO[6:1])
    // Chain snooping
    //
    // If Reserved byte is not $F or manufacturer id is $FFFF then no board is answering
    // Once this happens we can set ourselves up to talk to the next autoconfig query


    // Sniff board configuration sizes so we can shrink our offering appropriately
    'h00>>1:
     board_reg00 <= dbus_latched;
    'h02>>1:
     board_reg01 <= dbus_latched;

    'h0C>>1:
      if (!(dbus_latched == 4'hF)) begin // Reserved byte - Should be $FF
        snoop_cfg_next <= 1;
      end
    'h10>>1:
      if (dbus_latched == 4'hF) begin // Manufacturer ID - Should not be $FFFF
        mfg_bad[3] <= 1;
      end
    'h12>>1:
      if (dbus_latched == 4'hF) begin // Manufacturer ID - Should not be $FFFF
        mfg_bad[2] <= 1;
      end
    'h14>>1:
      if (dbus_latched == 4'hF) begin // Manufacturer ID - Should not be $FFFF
        mfg_bad[1] <= 1;
      end
    'h16>>1:
      if (dbus_latched == 4'hF) begin // Manufacturer ID - Should not be $FFFF
        mfg_bad[0] <= 1;
      end
    'h3C>>1:
      if (snoop_cfg_next == 1) begin
       snoop_cfg <= 1;
      end else if (mfg_bad[3:0] == 4'b1111) begin
       snoop_cfg <= 1;
      end
    endcase
  end else if (ADDR_HI[23:16] == 8'hE8 & !RWn & !snoop_cfg) begin
    // The other board is now being given it's address
    // Adjust our offering appropriately
    if (ADDR_LO[6:1] == 'h48>>1) begin
      if (board_reg00[3:2] == 2'b11) begin
        case (board_reg01[2:0])
          3'b000: // 8MB
          snooped_autoconfig_state <= SHUTUP;
         3'b100, 3'b101, 3'b110: // 512k/1/2MB
           if (snooped_autoconfig_state < SHUTUP) begin
            snooped_autoconfig_state <= snooped_autoconfig_state + 1;
           end
         3'b111: // 4MB
           if (snooped_autoconfig_state < Offer_Block3) begin
            snooped_autoconfig_state <= snooped_autoconfig_state + 2;
           end else begin
            snooped_autoconfig_state <= SHUTUP;
           end
        endcase
      end
    end
  end
end

reg [2:0] autoconfig_state;
`else
reg cdtv_configured;

// CDTV DMAC is first in chain.
// So we wait until it's configured before we talk
always @(negedge UDSn or negedge RESETn)
begin
    if (!RESETn) begin
      cdtv_configured <= 1'b0;
    end else begin
    if (ADDR_HI[23:16] == 8'hE8 & ADDR_LO[6:1] == 8'h24 & !ASn & !RWn) begin
      cdtv_configured <= 1'b1;
    end
  end
end
`endif

assign DBUS[15:12] = (autoconfig_cycle & RWn & !ASn & !UDSn) ? data_out[3:0] : 4'bZ;

`ifndef cdtv
assign autoconfig_cycle = (ADDR_HI[23:16] == 8'hE8) & snoop_cfg & CFGOUTn;
`else
assign autoconfig_cycle = (ADDR_HI[23:16] == 8'hE8) & CFGOUTn & cdtv_configured;
`endif

// Register Config in/out at end of bus cycle
always @(posedge ASn or negedge RESETn)
begin
  if (!RESETn) begin
    CFGOUTn <= 1'b1;
  end else begin
    CFGOUTn <= !shutup;
  end
end

// Offer up to 8MB in 2MB Blocks
always @(posedge CLK or negedge RESETn)
begin
  if (!RESETn) begin
    data_out <= 'bZ;
  end else if (autoconfig_cycle & RWn) begin
    case (ADDR_LO[6:1])      
      'h00:   data_out <= 4'b1110;
`ifndef cdtv
      'h01:   data_out <= 4'b0110; // 2MB
`else
      'h01:   data_out <= 4'b0000; // 8MB
`endif
      'h02:   data_out <= ~prod_id[7:4]; // Product number
      'h03:   data_out <= ~prod_id[3:0]; // Product number
      'h04:   data_out <= ~4'b1000;
      'h05:   data_out <= ~4'b0000;
      'h08:   data_out <= ~mfg_id[15:12]; // Manufacturer ID
      'h09:   data_out <= ~mfg_id[11:8];  // Manufacturer ID
      'h0A:   data_out <= ~mfg_id[7:4];   // Manufacturer ID
      'h0B:   data_out <= ~mfg_id[3:0];   // Manufacturer ID
      'h10:   data_out <= ~serial[15:12]; // Serial number
      'h11:   data_out <= ~serial[11:8];  // Serial number
      'h12:   data_out <= ~serial[7:4];   // Serial number
      'h13:   data_out <= ~serial[3:0];   // Serial number
      'h20:   data_out <= 4'b0;
      'h21:   data_out <= 4'b0;
      default: data_out <= 4'hF;
    endcase
  end
end
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

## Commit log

2021-02-04 Autoconfig improvements * Add CFGIN * Add hardware to hide autoconfig cycles until configured - Config before others - No need for cfgout - No need for cfgin if you want it to be the first dev config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
    As of yet untested, waiting on parts and need to adapt code :)
    [OpenAmiga500FastRamExpansion.kicad_pcb, OpenAmiga500FastRamExpansion.sch]
2021-02-13 Isolate /AS too
    [OpenAmiga500FastRamExpansion.kicad_pcb, OpenAmiga500FastRamExpansion.sch]
2021-02-14 Add V2 Firmware, update documentation
    [OpenAmiga500FastRamExpansion.kicad_pcb, OpenAmiga500FastRamExpansion.sch]
2021-02-16 Fixup schematic + documentation
    [OpenAmiga500FastRamExpansion.kicad_pcb, OpenAmiga500FastRamExpansion.sch]

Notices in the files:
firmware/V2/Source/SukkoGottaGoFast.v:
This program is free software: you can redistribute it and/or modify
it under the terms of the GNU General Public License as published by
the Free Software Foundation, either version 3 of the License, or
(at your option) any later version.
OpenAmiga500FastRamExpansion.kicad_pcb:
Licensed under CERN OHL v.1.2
